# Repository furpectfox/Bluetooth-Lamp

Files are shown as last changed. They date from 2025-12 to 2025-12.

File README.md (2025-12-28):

# Bluetooth-Lamp
A floor lamp controlled with your smartphone via bluetooth

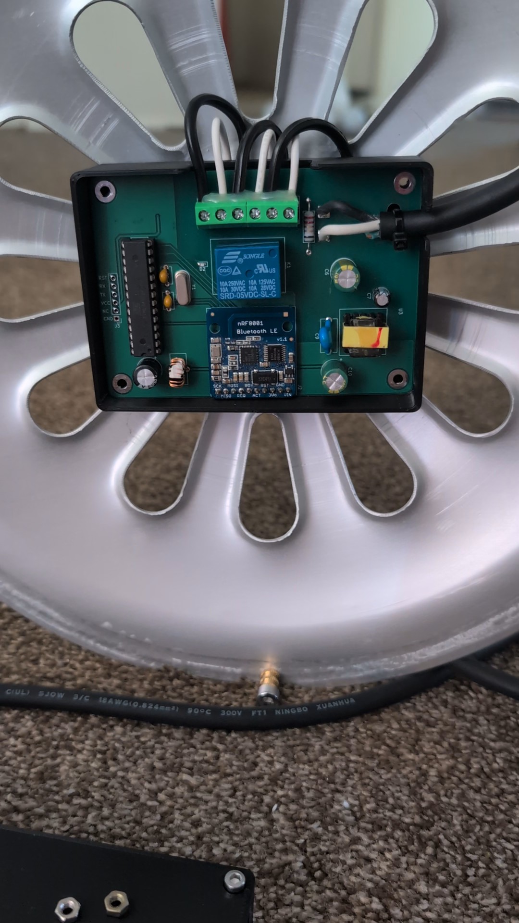
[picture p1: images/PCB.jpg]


## Schematic
[Flyback Converter Circuit](KiCad/BLE_Lamp-Flyback_Converter.pdf)

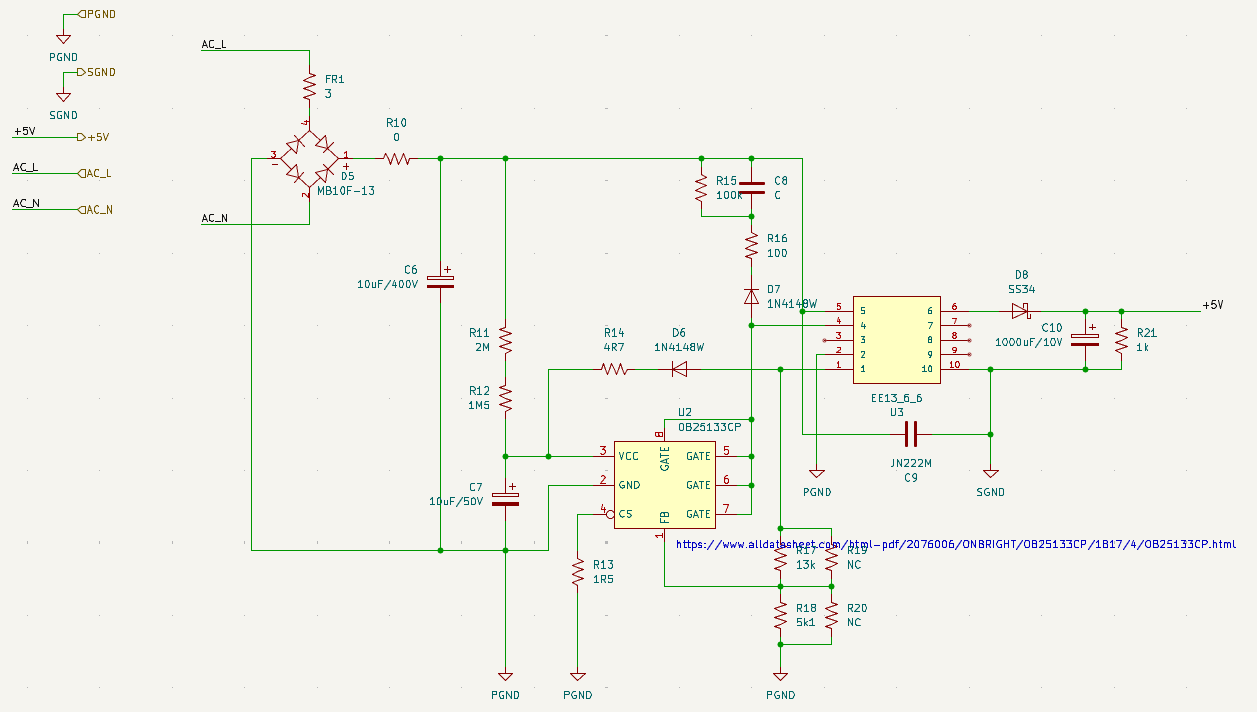
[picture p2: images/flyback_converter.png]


[Bluetooth Circuit](KiCad/BLE_Lamp.pdf)

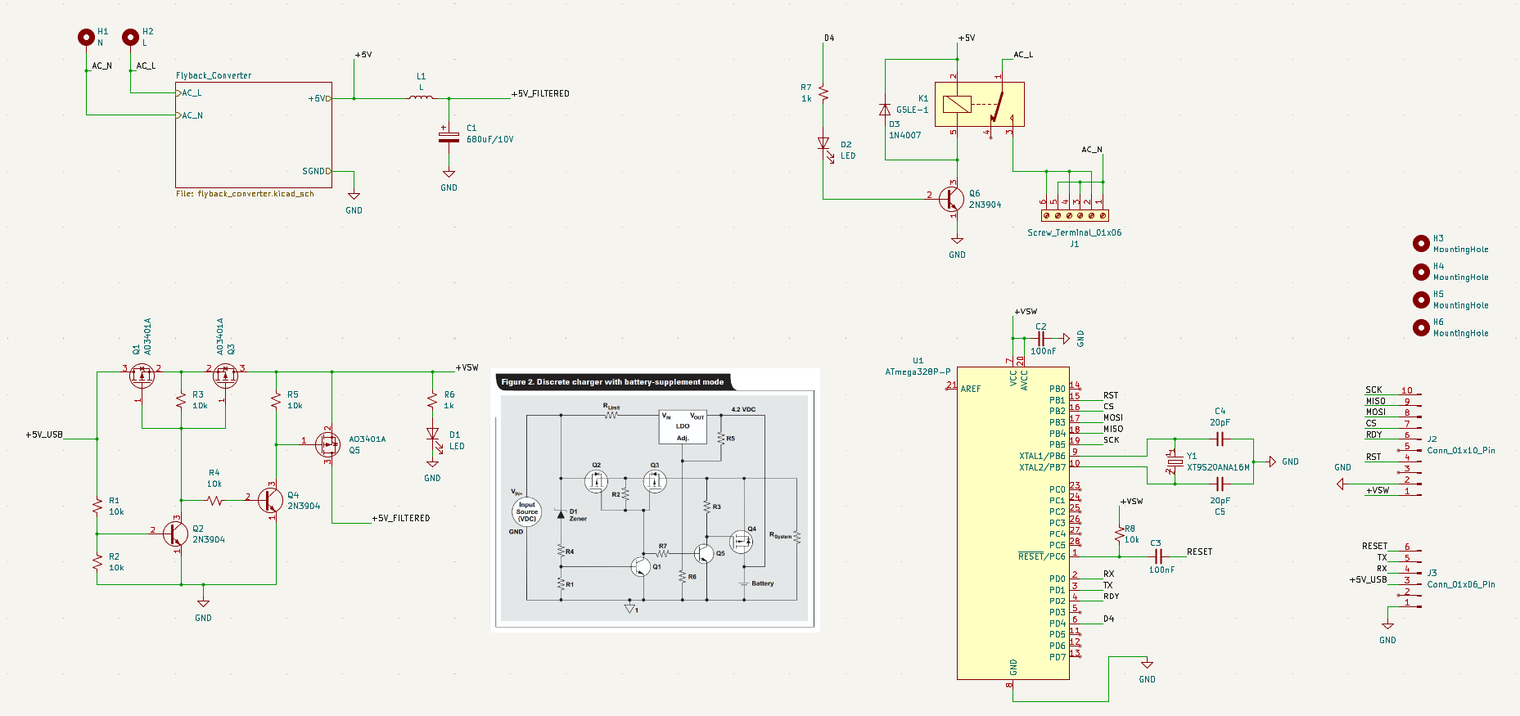
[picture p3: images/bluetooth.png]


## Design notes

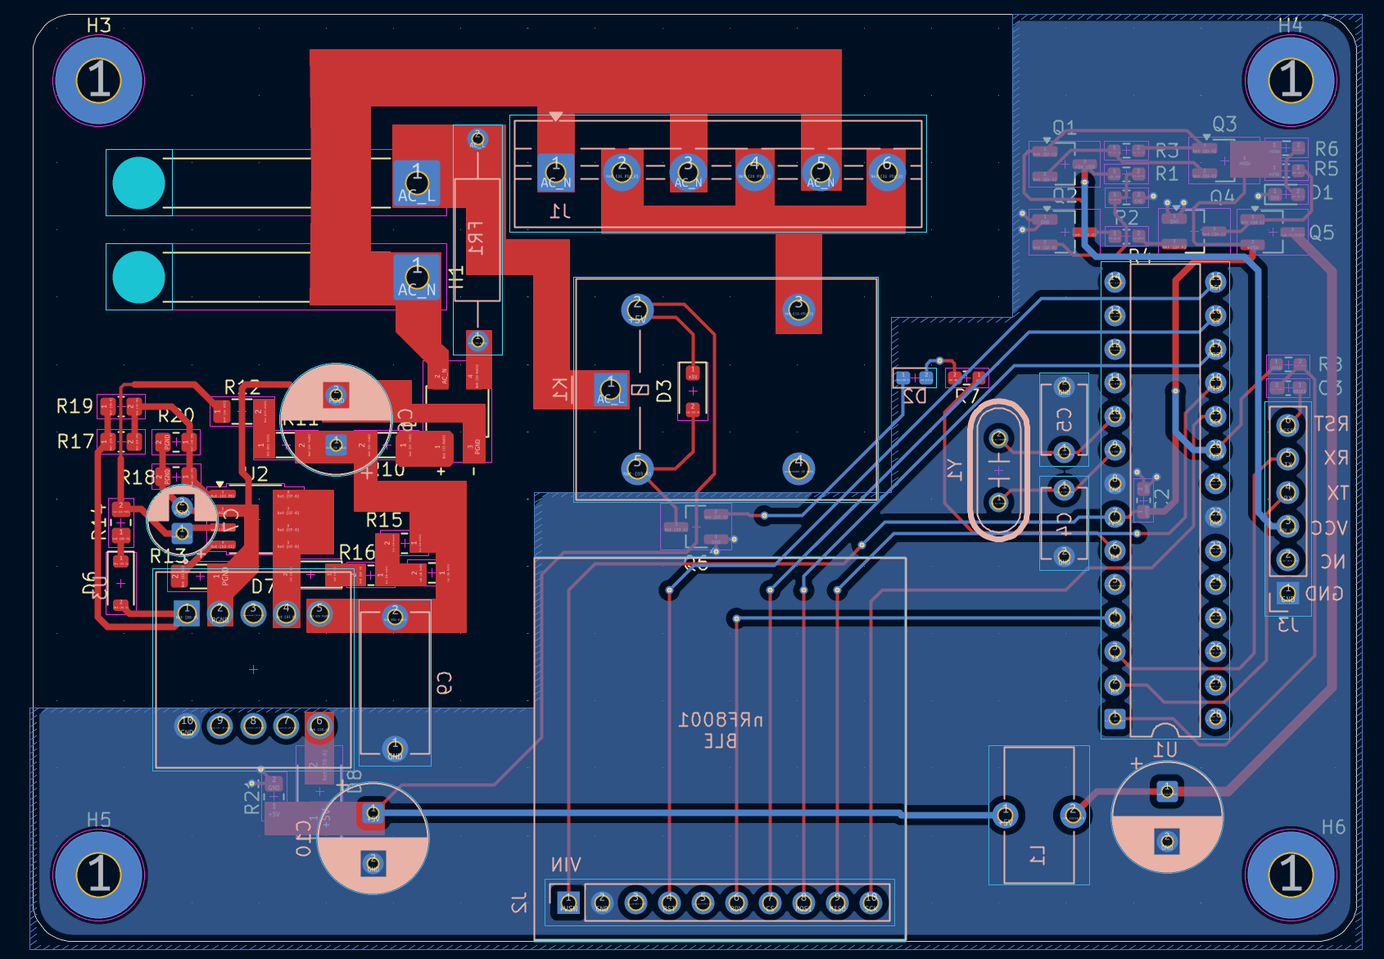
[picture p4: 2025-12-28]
images/pcb.png

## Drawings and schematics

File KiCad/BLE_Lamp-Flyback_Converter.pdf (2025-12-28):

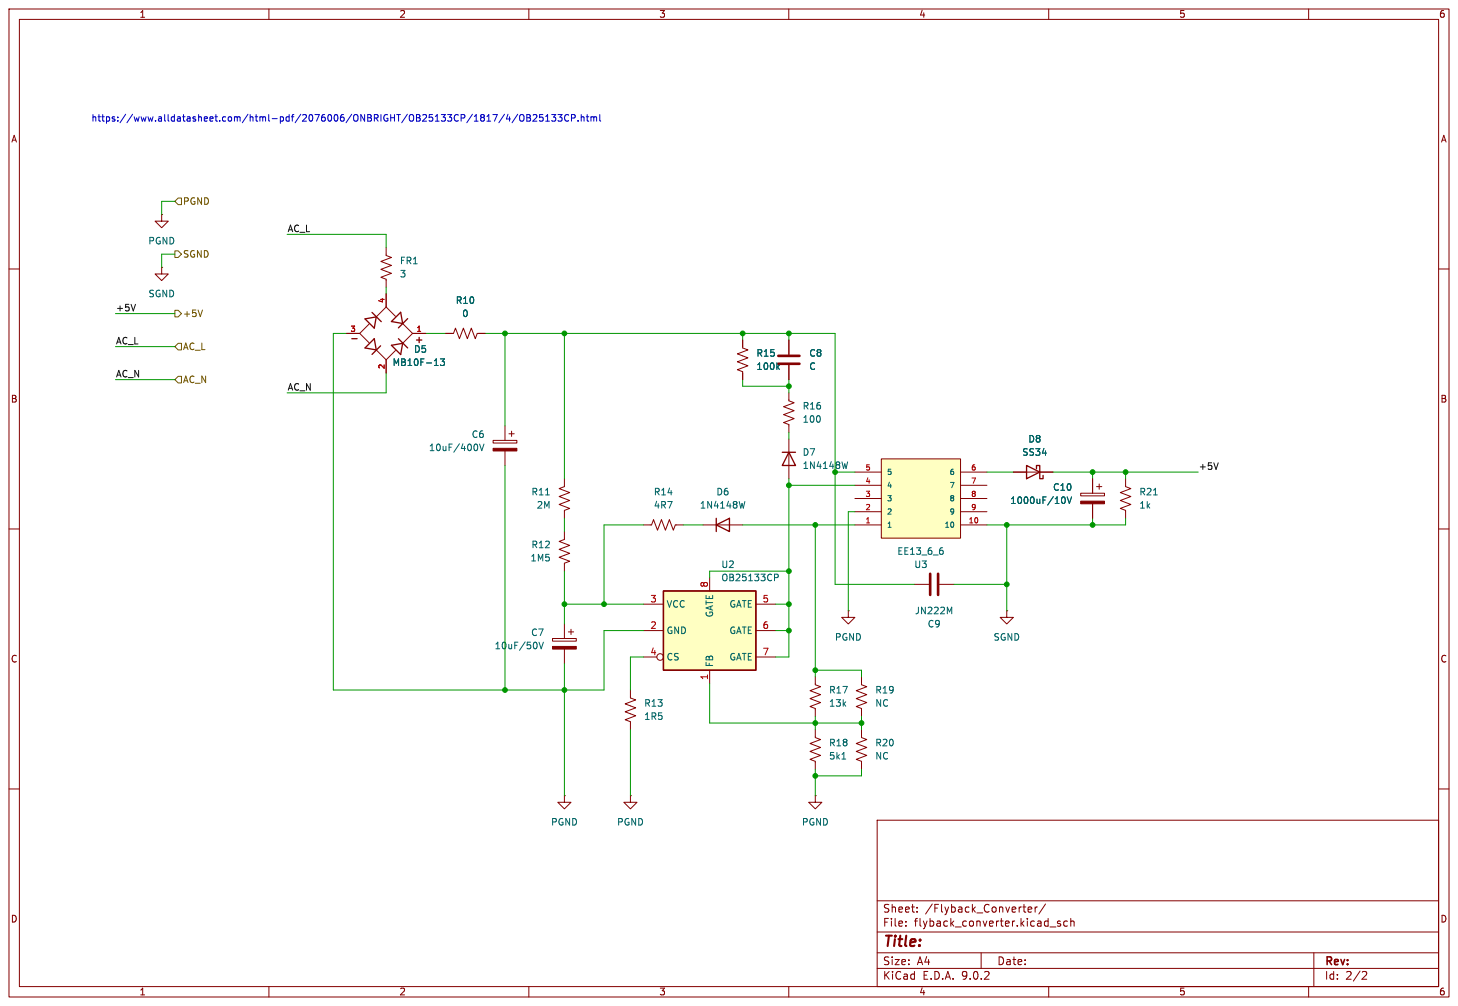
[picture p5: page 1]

1 VCC 3 GND 2 CS 4 GATE 5 GATE 6 GATE 7 U2 OB25133CP R10

Id: 2/2 Title: File: flyback_converter.kicad_sch Sheet: /Flyback_Converter/ PGND

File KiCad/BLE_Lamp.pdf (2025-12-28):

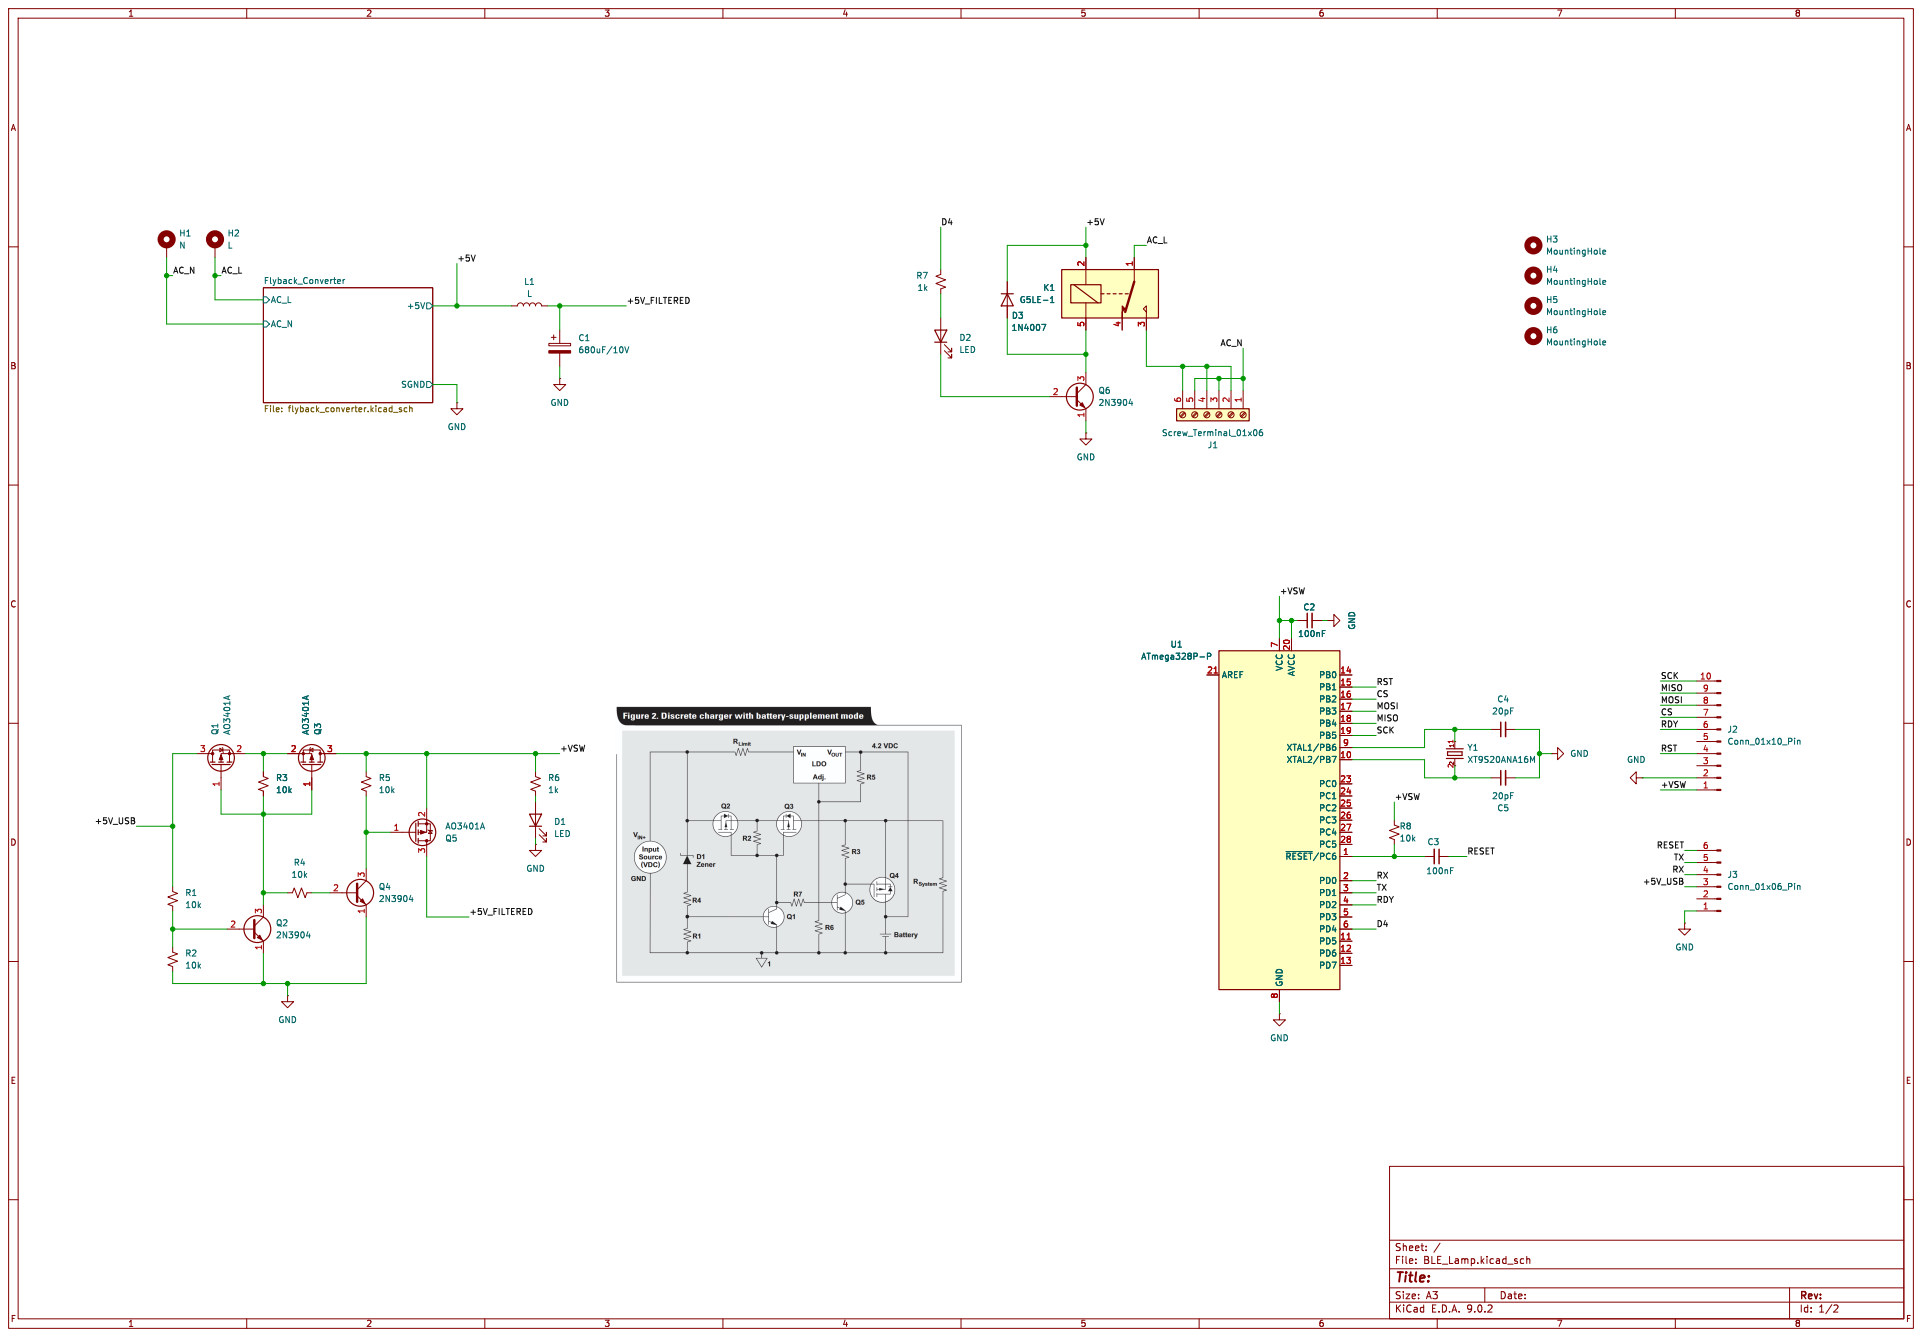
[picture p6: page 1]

D4 RDY MISO MOSI CS

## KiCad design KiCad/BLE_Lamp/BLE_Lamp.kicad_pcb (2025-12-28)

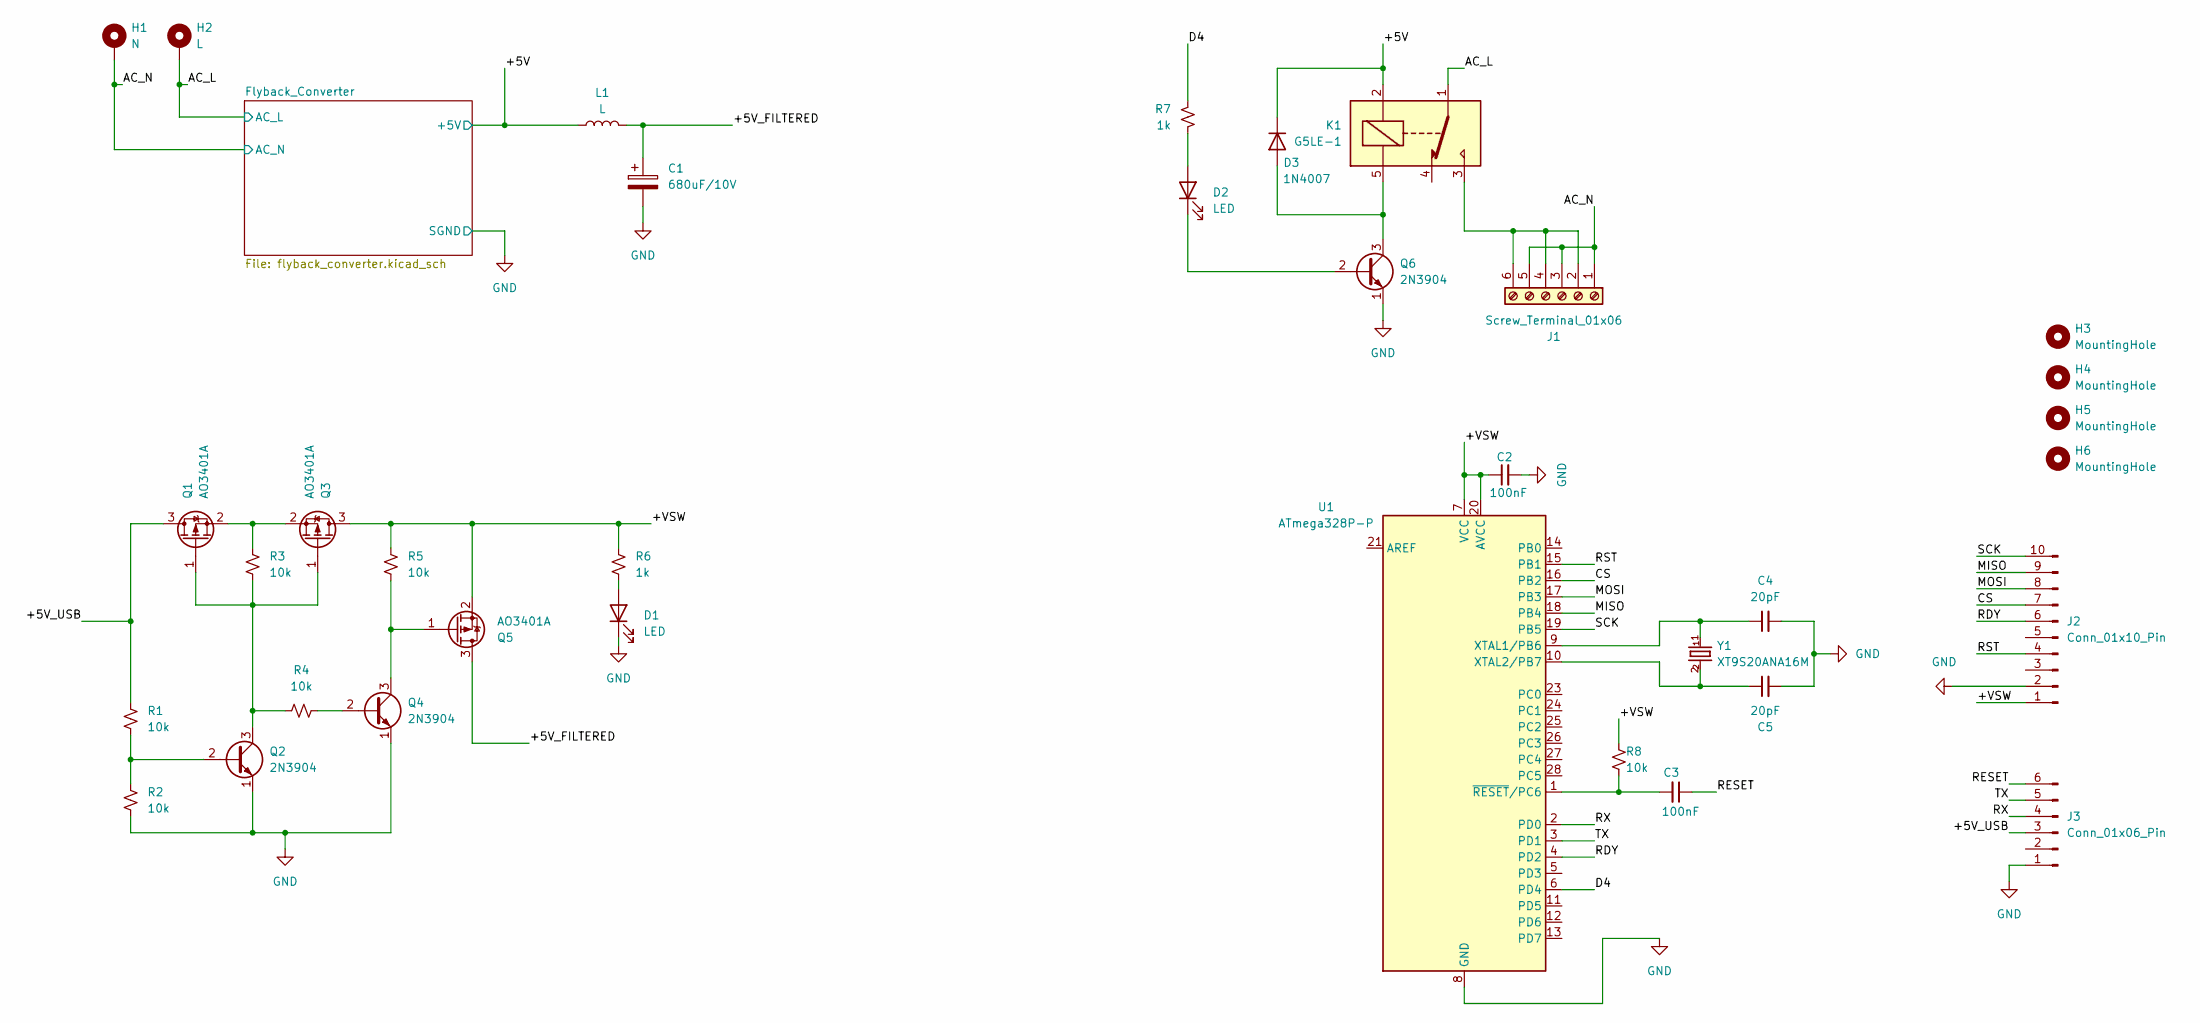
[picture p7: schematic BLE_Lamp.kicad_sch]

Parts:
C1: 680uF/10V; CP_Radial_D8.0mm_P3.80mm
C2, C3: 100nF; C_0603_1608Metric_Pad1.08x0.95mm_HandSolder
C4, C5: 20pF; C_Disc_D5.1mm_W3.2mm_P5.00mm
D1, D2: LED; LED_0603_1608Metric_Pad1.05x0.95mm_HandSolder
D3: 1N4007; D_SOD-123F
H1: N; SolderWire-0.75sqmm_1x01_D1.25mm_OD3.5mm_Relief
H2: L; SolderWire-0.75sqmm_1x01_D1.25mm_OD3.5mm_Relief
H3, H4, H5, H6: MountingHole; MountingHole_3.2mm_M3_Pad
J1: Screw_Terminal_01x06; TerminalBlock_MaiXu_MX126-5.0-06P_1x06_P5.00mm
J2: Conn_01x10_Pin; PinHeader_1x10_P2.54mm_Vertical
J3: Conn_01x06_Pin; PinHeader_1x06_P2.54mm_Vertical
K1: G5LE-1; Relay_SPDT_Omron-G5LE-1
L1: L; L_Toroid_Vertical_L10.0mm_W5.0mm_P5.08mm
Q1, Q3, Q5: AO3401A; SOT-23_Handsoldering
Q2, Q4, Q6: 2N3904; SOT-23_Handsoldering
R1, R2, R3, R4, R5, R8: 10k; R_0603_1608Metric_Pad0.98x0.95mm_HandSolder
R6, R7: 1k; R_0603_1608Metric_Pad0.98x0.95mm_HandSolder
U1: ATmega328P-P; DIP-28_W7.62mm
Y1: XT9S20ANA16M; XTAL_XT9S20ANA16M

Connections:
/+5V: D3.1 (K), K1.2, L1.1; also elsewhere on the board
/+5V_FILTERED: C1.1, L1.2, Q5.3 (D)
/+5V_USB: J3.3, Q1.3 (D), R1.1
/+VSW: C2.1, J2.1, Q3.3 (D), Q5.2 (S), R5.1, R6.1, R8.1, U1.7 (VCC), U1.20 (AVCC)
/AC_L: H2.1, K1.1; also elsewhere on the board
/AC_N: H1.1, J1.1, J1.3, J1.5; also elsewhere on the board
/CS: J2.7, U1.16 (PB2)
/D4: R7.1, U1.6 (PD4)
/MISO: J2.9, U1.18 (PB4)
/MOSI: J2.8, U1.17 (PB3)
/RDY: J2.6, U1.4 (PD2)
/RESET: C3.1, J3.6
/RST: J2.4, U1.15 (PB1)
/RX: J3.4, U1.2 (PD0)
/SCK: J2.10, U1.19 (PB5)
/TX: J3.5, U1.3 (PD1)
GND: C1.2, C2.2, C4.2, C5.2, D1.1 (K), J2.2, J3.1, Q2.1 (E), Q4.1 (E), Q6.1 (E), R2.2, U1.8 (GND), U1.22 (GND); also elsewhere on the board
unnamed: D1.2 (A), R6.2
unnamed: D2.2 (A), R7.2
unnamed: D2.1 (K), Q6.2 (B)
unnamed: D3.2 (A), K1.5, Q6.3 (C)
unnamed: J1.2, J1.4, J1.6, K1.3
unnamed: Q1.1 (G), Q2.3 (C), Q3.1 (G), R3.2, R4.1
unnamed: Q1.2 (S), Q3.2 (S), R3.1
unnamed: Q2.2 (B), R1.2, R2.1
unnamed: Q4.2 (B), R4.2
unnamed: Q4.3 (C), Q5.1 (G), R5.2
unnamed: C4.1, U1.9 (XTAL1/PB6), Y1.1
unnamed: C5.1, U1.10 (XTAL2/PB7), Y1.2
unnamed: C3.2, R8.2, U1.1 (~RESET/PC6)

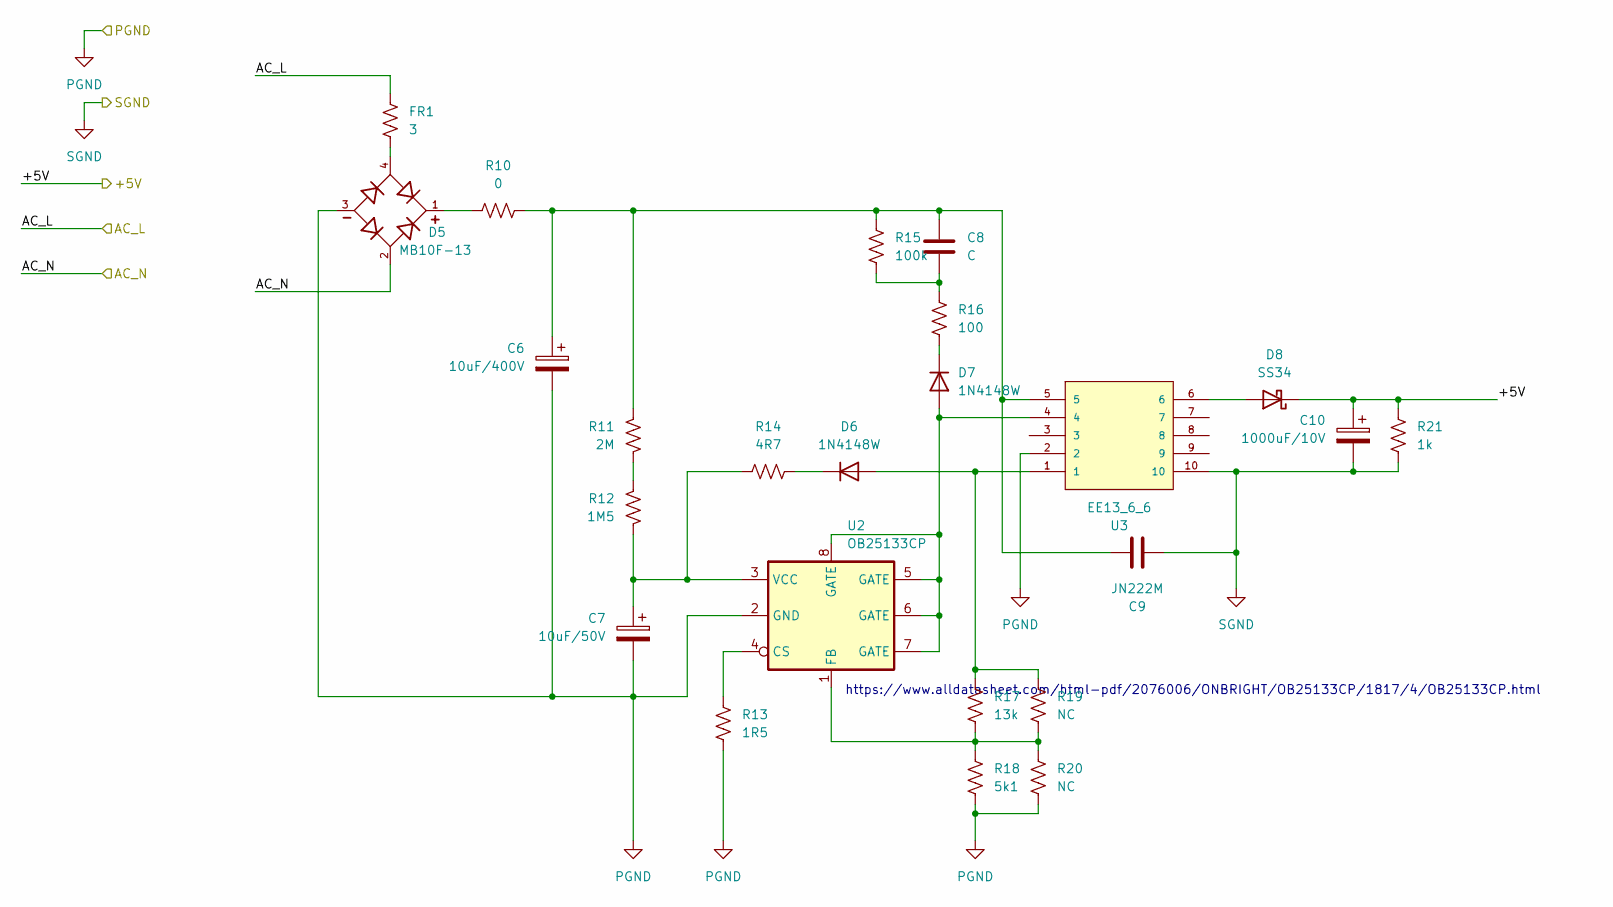
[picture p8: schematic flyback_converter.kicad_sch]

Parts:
C6: 10uF/400V; CP_Radial_D8.0mm_P3.80mm
C7: 10uF/50V; CP_Radial_D5.0mm_P2.00mm
C8: C; C_0805_2012Metric_Pad1.18x1.45mm_HandSolder
C9: JN222M; C_Disc_D10.5mm_W5.0mm_P10.00mm
C10: 1000uF/10V; CP_Radial_D8.0mm_P3.80mm
D5: MB10F-13; DIOB_MB10F-13; PARTREV 3 - 2
D6, D7: 1N4148W; D_SOD-123
D8: SS34; D_SMA
FR1: 3; R_Axial_DIN0309_L9.0mm_D3.2mm_P15.24mm_Horizontal
R10: 0; R_1206_3216Metric_Pad1.30x1.75mm_HandSolder
R11: 2M; R_1206_3216Metric_Pad1.30x1.75mm_HandSolder
R12: 1M5; R_1206_3216Metric_Pad1.30x1.75mm_HandSolder
R13: 1R5; R_1206_3216Metric_Pad1.30x1.75mm_HandSolder
R14: 4R7; R_0805_2012Metric_Pad1.20x1.40mm_HandSolder
R15: 100k; R_0805_2012Metric_Pad1.20x1.40mm_HandSolder
R16: 100; R_0805_2012Metric_Pad1.20x1.40mm_HandSolder
R17: 13k; R_0805_2012Metric_Pad1.20x1.40mm_HandSolder
R18: 5k1; R_0805_2012Metric_Pad1.20x1.40mm_HandSolder
R19, R20: NC; R_0805_2012Metric_Pad1.20x1.40mm_HandSolder
R21: 1k; R_0805_2012Metric_Pad1.20x1.40mm_HandSolder
U2: OB25133CP; SOIC-8_3.9x4.9mm_P1.27mm
U3: EE13_6_6; BOBBIN_EE13_6_6; PARTREV 11/19

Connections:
/+5V: C10.1, D8.1 (K), R21.1; also elsewhere on the board
/AC_L: FR1.2; also elsewhere on the board
/AC_N: D5.2; also elsewhere on the board
GND: C9.1, C10.2, R21.2, U3.10; also elsewhere on the board
unnamed: C6.1, C8.1, C9.2, R10.2, R11.2, R15.1, U3.5
unnamed: C8.2, R15.2, R16.1
unnamed: D5.1, R10.1
unnamed: D5.4, FR1.1
unnamed: D6.2 (A), R17.1, R19.1, U3.1
unnamed: D6.1 (K), R14.1
unnamed: D7.2 (A), U2.5 (GATE), U2.6 (GATE), U2.7 (GATE), U2.8 (GATE), U3.4
unnamed: D7.1 (K), R16.2
unnamed: D8.2 (A), U3.6
unnamed: R11.1, R12.2
unnamed: R13.2, U2.4 (CS)
unnamed: R17.2, R18.1, R19.2, R20.1, U2.1 (FB)
unnamed: C7.1, R12.1, R14.2, U2.3 (VCC)
PGND: C6.2, C7.2, D5.3, R13.1, R18.2, R20.2, U2.2 (GND), U3.2

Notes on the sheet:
https://www.alldatasheet.com/html-pdf/2076006/ONBRIGHT/OB25133CP/1817/4/OB25133CP.html

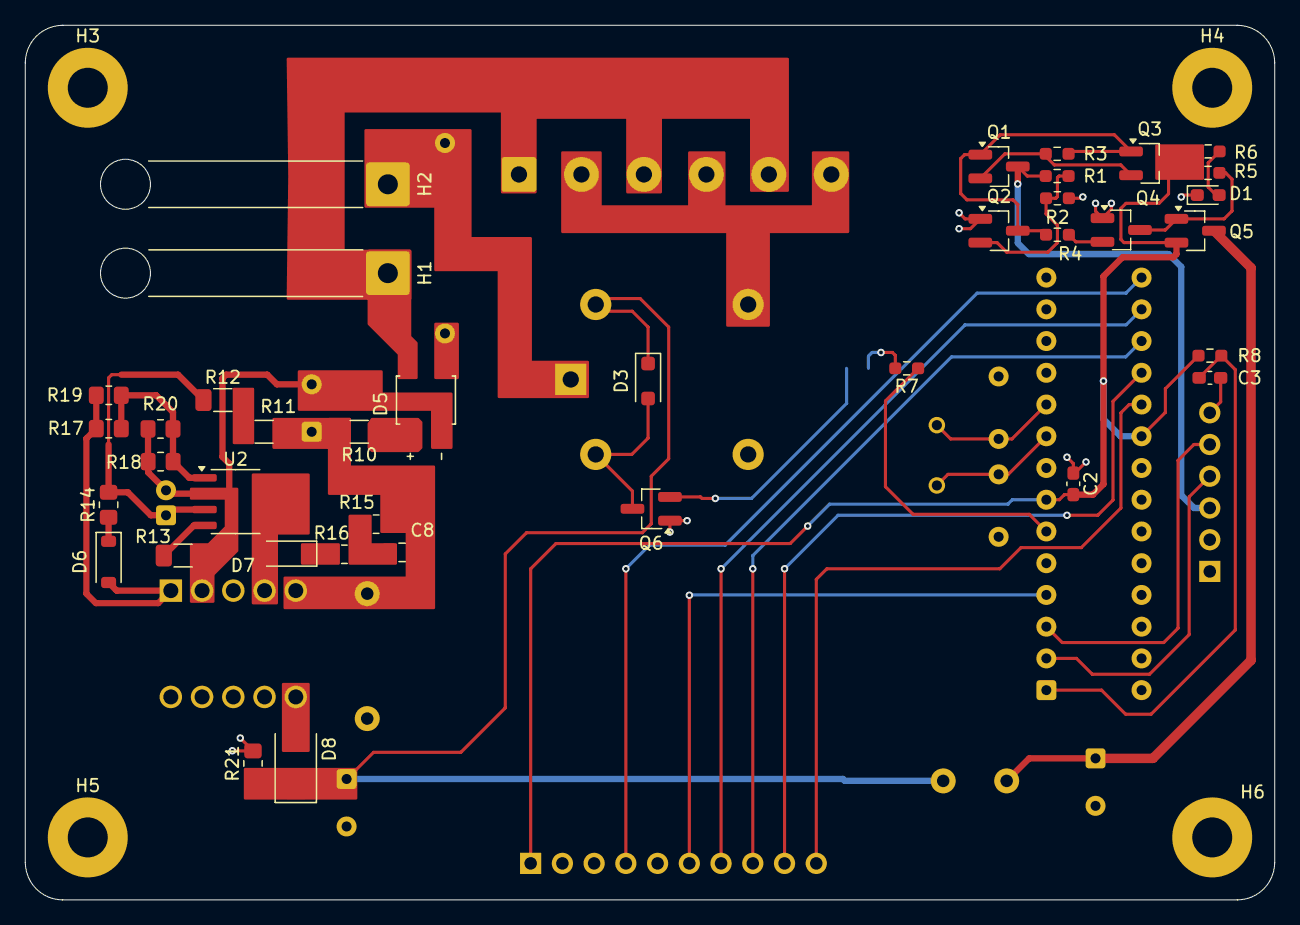
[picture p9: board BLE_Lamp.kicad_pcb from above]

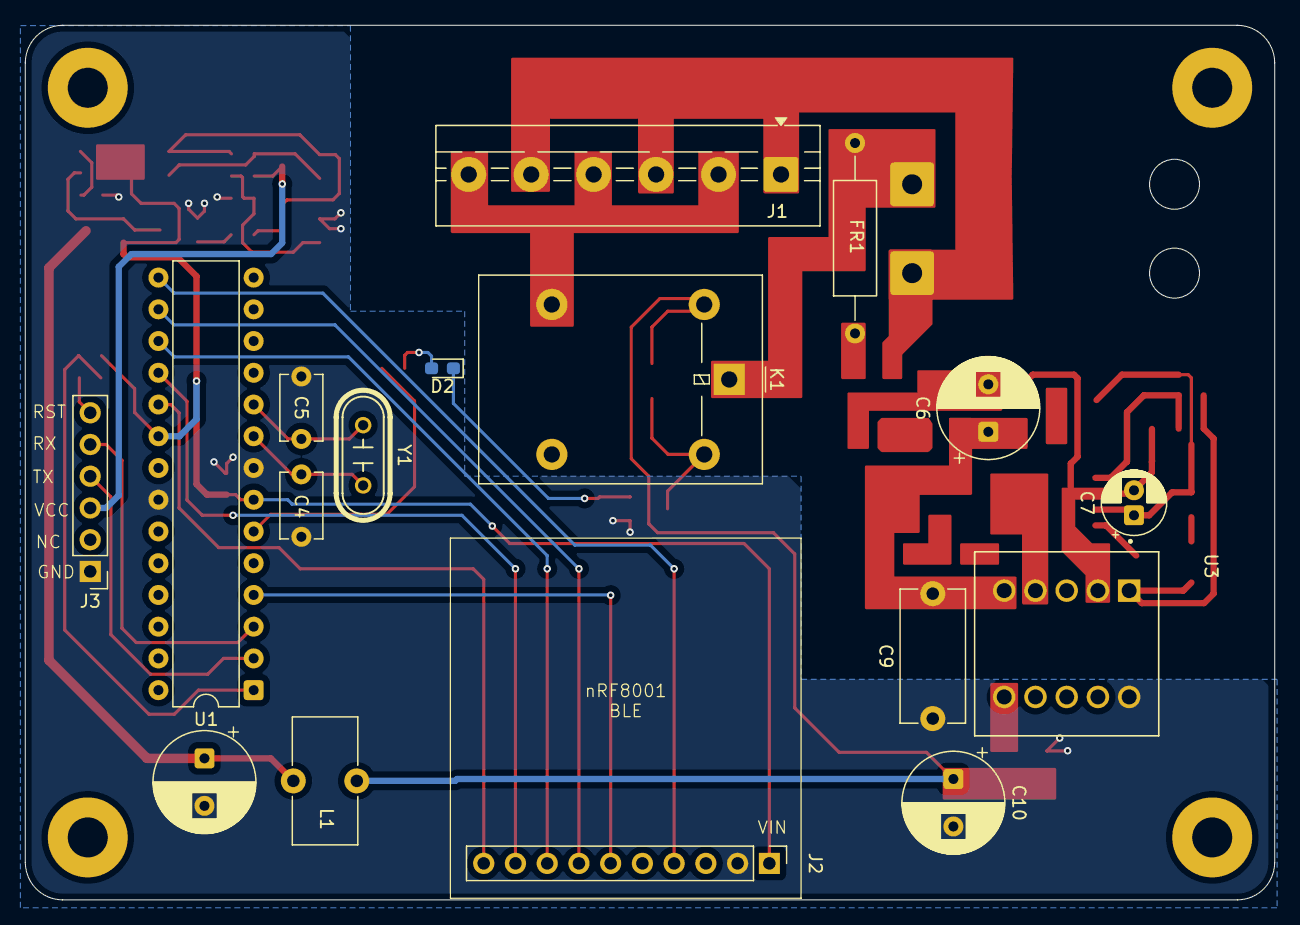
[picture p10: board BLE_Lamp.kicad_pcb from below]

Board: 2 copper layers, 100.0 x 70.0 mm, 59 parts (17 on the bottom side), 44 nets.

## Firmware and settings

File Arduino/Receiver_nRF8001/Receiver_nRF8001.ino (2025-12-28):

/*********************************************************************
This is an example for our nRF8001 Bluetooth Low Energy Breakout

  Pick one up today in the adafruit shop!
  ------> http://www.adafruit.com/products/1697

Adafruit invests time and resources providing this open source code, 
please support Adafruit and open-source hardware by purchasing 
products from Adafruit!

Written by Kevin Townsend/KTOWN  for Adafruit Industries.
MIT license, check LICENSE for more information
All text above, and the splash screen below must be included in any redistribution
*********************************************************************/

// This version uses the internal data queing so you can treat it like Serial (kinda)!

#include <SPI.h>
#include "Adafruit_BLE_UART.h"

// Connect CLK/MISO/MOSI to hardware SPI
// e.g. On UNO & compatible: CLK = 13, MISO = 12, MOSI = 11
#define ADAFRUITBLE_REQ 10
#define ADAFRUITBLE_RDY 2     // This should be an interrupt pin, on Uno thats #2 or #3
#define ADAFRUITBLE_RST 9

Adafruit_BLE_UART BTLEserial = Adafruit_BLE_UART(ADAFRUITBLE_REQ, ADAFRUITBLE_RDY, ADAFRUITBLE_RST);

// 
const uint8_t relay_pin = 4;
/**************************************************************************/
/*!
    Configure the Arduino and start advertising with the radio
*/
/**************************************************************************/
void setup(void)
{ 
  Serial.begin(9600);
  while(!Serial); // Leonardo/Micro should wait for serial init
  Serial.println(F("Adafruit Bluefruit Low Energy nRF8001 Print echo demo"));

  // BTLEserial.setDeviceName("NEWNAME"); /* 7 characters max! */

  BTLEserial.begin();

  pinMode(relay_pin, OUTPUT);
  digitalWrite(relay_pin, HIGH);
}

/**************************************************************************/
/*!
    Constantly checks for new events on the nRF8001
*/
/**************************************************************************/
aci_evt_opcode_t laststatus = ACI_EVT_DISCONNECTED;

void loop()
{
  static char incoming_str[4] = "";
  static uint8_t i = 0;
  
  // Tell the nRF8001 to do whatever it should be working on.
  BTLEserial.pollACI();

  // Ask what is our current status
  aci_evt_opcode_t status = BTLEserial.getState();
  // If the status changed....
  if (status != laststatus) {
    // print it out!
    if (status == ACI_EVT_DEVICE_STARTED) {
        Serial.println(F("* Advertising started"));
    }
    if (status == ACI_EVT_CONNECTED) {
        Serial.println(F("* Connected!"));
    }
    if (status == ACI_EVT_DISCONNECTED) {
        Serial.println(F("* Disconnected or advertising timed out"));
    }
    // OK set the last status change to this one
    laststatus = status;
  }

  if (status == ACI_EVT_CONNECTED) {
    // Lets see if there's any data for us!
    if (BTLEserial.available()) {
      Serial.print("* "); Serial.print(BTLEserial.available()); Serial.println(F(" bytes available from BTLE"));
    }
    // OK while we still have something to read, get a character and print it out
    while (BTLEserial.available()) {
      char c = BTLEserial.read();
      incoming_str[i] = c;
      i++;
      Serial.print(c);
    }

    // Check what the incoming string is
    if (strcmp(incoming_str, "ON") == 0) {
      Serial.println();
      Serial.println(incoming_str);
      digitalWrite(relay_pin, HIGH);
      
    }

    if (strcmp(incoming_str, "OFF") == 0) {
      Serial.println();
      Serial.println(incoming_str);
      digitalWrite(relay_pin, LOW);
    }

    memset(incoming_str, 0, sizeof(incoming_str));
    i = 0;





    

    // Next up, see if we have any data to get from the Serial console

    if (Serial.available()) {
      // Read a line from Serial
      Serial.setTimeout(100); // 100 millisecond timeout
      String s = Serial.readString();

      // We need to convert the line to bytes, no more than 20 at this time
      uint8_t sendbuffer[20];
      s.getBytes(sendbuffer, 20);
      char sendbuffersize = min(20, s.length());

      Serial.print(F("\n* Sending -> \"")); Serial.print((char *)sendbuffer); Serial.println("\"");

      // write the data
      BTLEserial.write(sendbuffer, sendbuffersize);
    }
  }
}
